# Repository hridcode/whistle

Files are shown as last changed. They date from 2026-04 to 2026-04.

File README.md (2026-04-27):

# Whistle

Whistle is the devboard of all time. It shares many similarities with the Raspberry Pi Pico, having the RP2040 SoC on board. However, this board aims to improve on the Pico's shortcomings. No more dealing with the haunting micro-USB port! This board uses a USB-C connection port. It also has 1 extra ADC pin, as well as an inbuilt digital-to-analog converter (DAC) and mono speaker amplifier, making it perfect for audio-integrated projects!

Oh, I almost forgot, it has LiPo battery charging!

# Photos

|Schematic|PCB|3D Render|
|---|---|---|
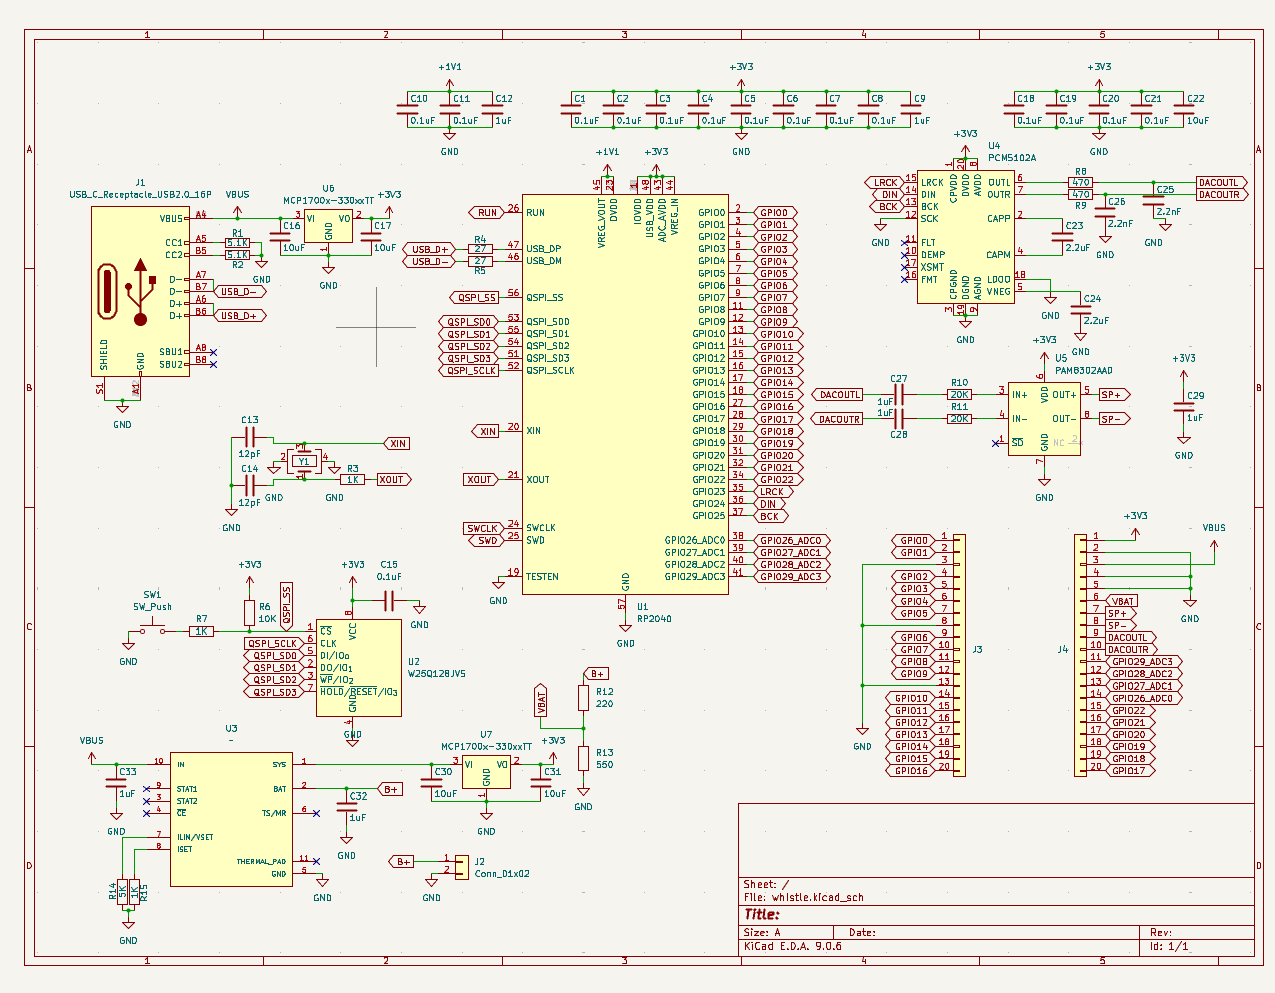
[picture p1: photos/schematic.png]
Schematic
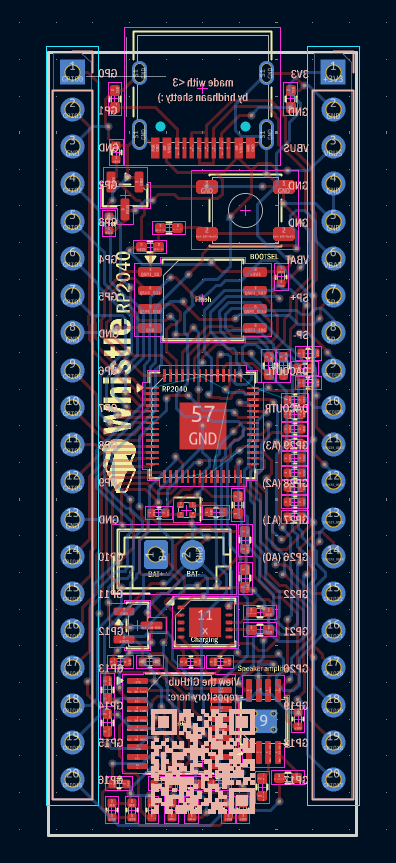
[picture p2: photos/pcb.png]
PCB
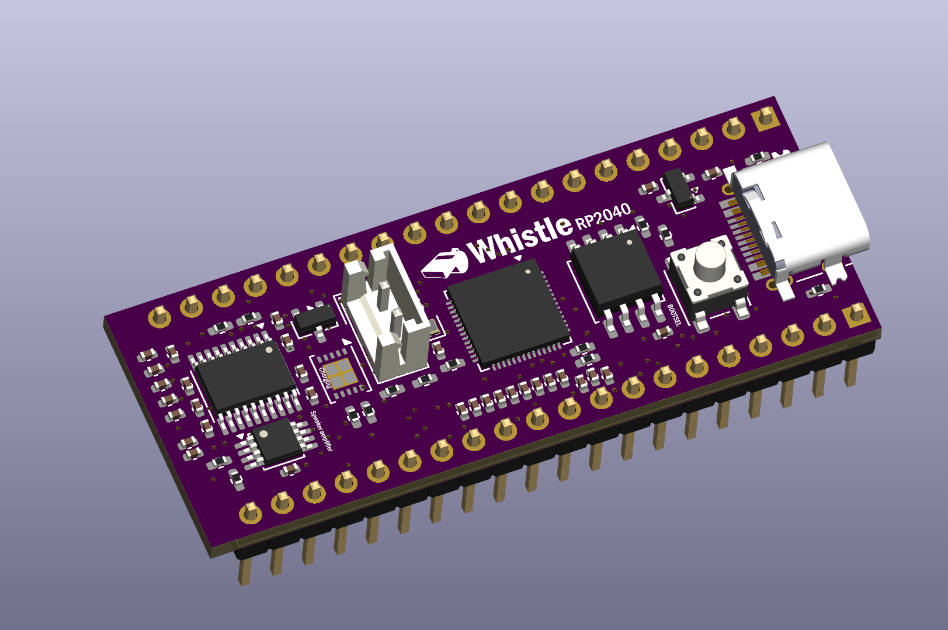
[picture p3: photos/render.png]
3D Render
||||

# BOM

|Item|Cost|Source|
|---|---|---|
|RP2040|$0.94|https://www.lcsc.com/product-detail/C2040.html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|
|Crystal oscillator|$0.07|https://www.lcsc.com/product-detail/C9002.html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|
|MCP1700 LDO, 3.3V|$0.98|https://www.lcsc.com/product-detail/C39051.html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|
|USB-C port, 16-pin|$0.08|https://www.lcsc.com/product-detail/C2988369.html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|
|W25Q128JVSIQ flash memory|$1.96|https://www.lcsc.com/product-detail/C97521.html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|
|PCM5102A DAC|$1.02|https://www.lcsc.com/product-detail/C107671.html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|
|PAM8302AAD speaker amplifier|$0.21|https://www.lcsc.com/product-detail/C112137.html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|
|BQ25185 battery charging IC|$1.66|https://www.lcsc.com/product-detail/C19725033.html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|
|SMD tactile switch, 6x6mm|$0.03|https://www.lcsc.com/product-detail/C49234152.html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|
|Pin headers|$0.38|https://www.lcsc.com/product-detail/C2938459.html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|
|PCB|$0.42|https://cart.jlcpcb.com/quote?stencilLayer=2&stencilWidth=21&stencilLength=54&stencilCounts=5&plateType=1|
|Stencil|$3.05|https://cart.jlcpcb.com/quote?stencilLayer=2&stencilWidth=21&stencilLength=54&stencilCounts=5&plateType=1|

Total: $10.81 ($7.76 w/o stencil)

# Notes

Have fun!

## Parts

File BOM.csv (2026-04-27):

Item | Cost | Source
RP2040 | 0.94 | https://www.lcsc.com/product-detail/C2040.html?s_z=s_p_RP2040
Crystal oscillator | 0.07 | https://www.lcsc.com/product-detail/C9002.html?s_z=s_q_CRYSTAL%252012MHZ
MCP1700 LDO (3.3V) | 0.98 | https://www.lcsc.com/product-detail/C39051.html?s_z=n_q_mcp1700%2520tt
USB-C port (16-pin) | 0.08 | https://www.lcsc.com/product-detail/C2988369.html?s_z=n_q_usb%2520c%252016
W25Q128JVSIQ flash memory | 1.96 | https://www.lcsc.com/product-detail/C97521.html?s_z=s_q_W25Q128JVSIQ
PCM5102A DAC | 1.02 | https://www.lcsc.com/product-detail/C107671.html?s_z=n_q_pcm5102a
PAM8302AAD speaker amplifier | 0.21 | https://www.lcsc.com/product-detail/C112137.html?s_z=n_q_pam8302aad
BQ25185 battery charging IC | 1.66 | https://www.lcsc.com/product-detail/C19725033.html?s_z=s_p_BQ25185DLHR
PCB | 0.42 | https://cart.jlcpcb.com/quote?stencilLayer=2&stencilWidth=21&stencilLength=54&stencilCounts=5&plateType=1
Stencil | 3.05 | https://cart.jlcpcb.com/quote?stencilLayer=2&stencilWidth=21&stencilLength=54&stencilCounts=5&plateType=1
SMD tactile switch (6x6mm) | 0.03 | https://www.lcsc.com/product-detail/C49234152.html?s_z=n_q_5x5mm%2520button
Pin headers | 0.24 | https://www.lcsc.com/product-detail/C2938459.html?s_z=h_q_pin%2520headers%252001x20
Total | 10.81

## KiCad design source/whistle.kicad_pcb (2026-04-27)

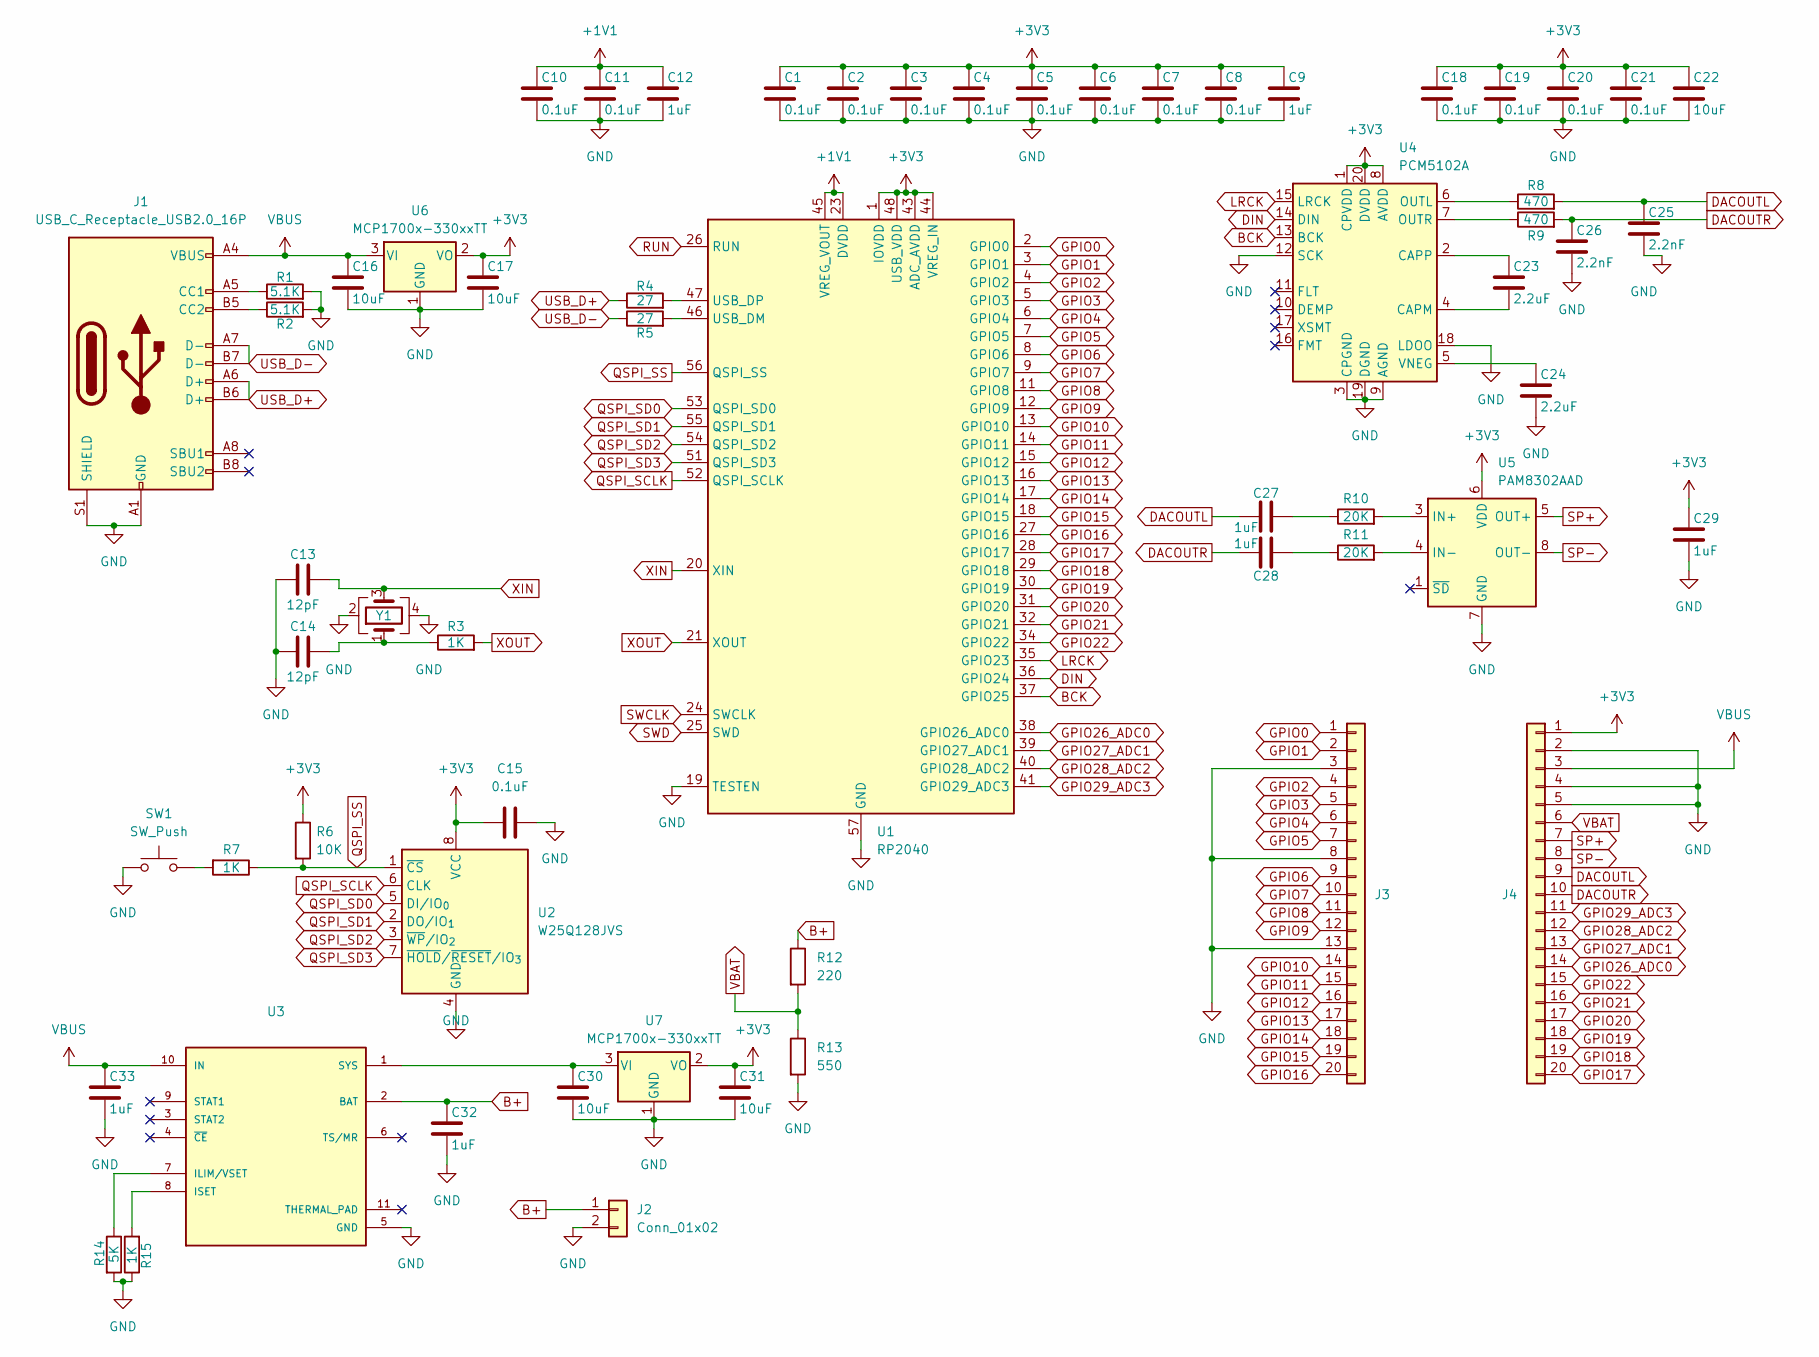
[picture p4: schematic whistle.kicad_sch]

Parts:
C1, C2, C3, C4, C5, C6, C7, C8, C10, C11, C15, C18, C19, C20, C21: 0.1uF; C_0402_1005Metric
C9, C12, C27, C28, C29, C32, C33: 1uF; C_0402_1005Metric
C13, C14: 12pF; C_0402_1005Metric
C16, C17, C22, C30, C31: 10uF; C_0402_1005Metric
C23, C24: 2.2uF; C_0402_1005Metric
C25, C26: 2.2nF; C_0402_1005Metric
J1: USB_C_Receptacle_USB2.0_16P; USB_C_Receptacle_HRO_TYPE-C-31-M-12
J2: Conn_01x02; JST_EH_B2B-EH-A_1x02_P2.50mm_Vertical
J3, J4: Conn_01x20; PinHeader_1x20_P2.54mm_Vertical
R1, R2: 5.1K; R_0402_1005Metric_Pad0.72x0.64mm_HandSolder
R3, R7, R15: 1K; R_0402_1005Metric_Pad0.72x0.64mm_HandSolder
R4, R5: 27; R_0402_1005Metric_Pad0.72x0.64mm_HandSolder
R6: 10K; R_0402_1005Metric_Pad0.72x0.64mm_HandSolder
R8, R9: 470; R_0402_1005Metric_Pad0.72x0.64mm_HandSolder
R10, R11: 20K; R_0402_1005Metric_Pad0.72x0.64mm_HandSolder
R12: 220; R_0402_1005Metric_Pad0.72x0.64mm_HandSolder
R13: 550; R_0402_1005Metric_Pad0.72x0.64mm_HandSolder
R14: 5K; R_0402_1005Metric_Pad0.72x0.64mm_HandSolder
SW1: SW_Push; SW_SPST_PTS647_Sx50
U1: RP2040; QFN-56-1EP_7x7mm_P0.4mm_EP3.2x3.2mm
U2: W25Q128JVS; SOIC-8_5.3x5.3mm_P1.27mm
U3: WSON-10-1EP_4x3mm_P0.5mm_EP2.2x2mm
U4: PCM5102A; TSSOP-20_4.4x6.5mm_P0.65mm
U5: PAM8302AAD; MSOP-8-1EP_3x3mm_P0.65mm_EP1.5x1.8mm_ThermalVias
U6, U7: MCP1700x-330xxTT; SOT-23
Y1: Crystal_GND24; Crystal_SMD_1210-4Pin_1.2x1.0mm

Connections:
+1V1: C10.1, C11.1, C12.1, U1.23 (DVDD), U1.45 (VREG_VOUT), U1.50 (DVDD)
+3V3: C1.1, C2.1, C3.1, C4.1, C5.1, C6.1, C7.1, C8.1, C9.1, C15.1, C17.1, C18.1, C19.1, C20.1, C21.1, C22.1, C29.1, C31.1, J4.1, R6.1, U1.1 (IOVDD), U1.10 (IOVDD), U1.22 (IOVDD), U1.33 (IOVDD), U1.42 (IOVDD), U1.43 (ADC_AVDD), U1.44 (VREG_IN), U1.48 (USB_VDD), U1.49 (IOVDD), U2.8 (VCC), U4.1 (CPVDD), U4.8 (AVDD), U4.20 (DVDD), U5.6 (VDD), U6.2 (VO), U7.2 (VO)
B+: C32.1, J2.1, R12.1, U3.2 (BAT)
BCK: U1.37 (GPIO25), U4.13 (BCK)
DACOUTL: C25.1, C27.1, J4.9, R8.2
DACOUTR: C26.1, C28.2, J4.10, R9.2
DIN: U1.36 (GPIO24), U4.14 (DIN)
GPIO0: J3.1, U1.2 (GPIO0)
GPIO1: J3.2, U1.3 (GPIO1)
GPIO2: J3.4, U1.4 (GPIO2)
GPIO3: J3.5, U1.5 (GPIO3)
GPIO4: J3.6, U1.6 (GPIO4)
GPIO5: J3.7, U1.7 (GPIO5)
GPIO6: J3.9, U1.8 (GPIO6)
GPIO7: J3.10, U1.9 (GPIO7)
GPIO8: J3.11, U1.11 (GPIO8)
GPIO9: J3.12, U1.12 (GPIO9)
GPIO10: J3.14, U1.13 (GPIO10)
GPIO11: J3.15, U1.14 (GPIO11)
GPIO12: J3.16, U1.15 (GPIO12)
GPIO13: J3.17, U1.16 (GPIO13)
GPIO14: J3.18, U1.17 (GPIO14)
GPIO15: J3.19, U1.18 (GPIO15)
GPIO16: J3.20, U1.27 (GPIO16)
GPIO17: J4.20, U1.28 (GPIO17)
GPIO18: J4.19, U1.29 (GPIO18)
GPIO19: J4.18, U1.30 (GPIO19)
GPIO20: J4.17, U1.31 (GPIO20)
GPIO21: J4.16, U1.32 (GPIO21)
GPIO22: J4.15, U1.34 (GPIO22)
GPIO26_ADC0: J4.14, U1.38 (GPIO26_ADC0)
GPIO27_ADC1: J4.13, U1.39 (GPIO27_ADC1)
GPIO28_ADC2: J4.12, U1.40 (GPIO28_ADC2)
GPIO29_ADC3: J4.11, U1.41 (GPIO29_ADC3)
LRCK: U1.35 (GPIO23), U4.15 (LRCK)
unnamed: C14.2, R3.1, Y1.1
unnamed: C27.2, R10.1
unnamed: C28.1, R11.1
unnamed: J1.A5 (CC1), R1.1
unnamed: J1.B5 (CC2), R2.1
unnamed: R7.2, SW1.2
unnamed: R5.2, U1.46 (USB_DM)
unnamed: R4.2, U1.47 (USB_DP)
unnamed: R14.1, U3.7 (ILIM/VSET)
unnamed: R15.2, U3.8 (ISET)
unnamed: C30.1, U3.1 (SYS), U7.3 (VI)
unnamed: C23.2, U4.4 (CAPM)
unnamed: C23.1, U4.2 (CAPP)
unnamed: R8.1, U4.6 (OUTL)
unnamed: R9.1, U4.7 (OUTR)
unnamed: R10.2, U5.3 (IN+)
unnamed: R11.2, U5.4 (IN-)
QSPI_SCLK: U1.52 (QSPI_SCLK), U2.6 (CLK)
QSPI_SD0: U1.53 (QSPI_SD0), U2.5 (DI/IO_{0})
QSPI_SD1: U1.55 (QSPI_SD1), U2.2 (DO/IO_{1})
QSPI_SD2: U1.54 (QSPI_SD2), U2.3 (~WP/IO_{2})
QSPI_SD3: U1.51 (QSPI_SD3), U2.7 (~HOLD/~RESET/IO_{3})
QSPI_SS: R6.2, R7.1, U1.56 (QSPI_SS), U2.1 (~CS)
RUN: U1.26 (RUN)
SP+: J4.7, U5.5 (OUT+)
SP-: J4.8, U5.8 (OUT-)
SWCLK: U1.24 (SWCLK)
SWD: U1.25 (SWD)
USB_D+: J1.A6 (D+), J1.B6 (D+), R4.1
USB_D-: J1.A7 (D-), J1.B7 (D-), R5.1
VBAT: J4.6, R12.2, R13.1
VBUS: C16.1, C33.1, J1.A4 (VBUS), J1.A9 (VBUS), J1.B4 (VBUS), J1.B9 (VBUS), J4.3, U3.10 (IN), U6.3 (VI)
XIN: C13.2, U1.20 (XIN), Y1.3
XOUT: R3.2, U1.21 (XOUT)

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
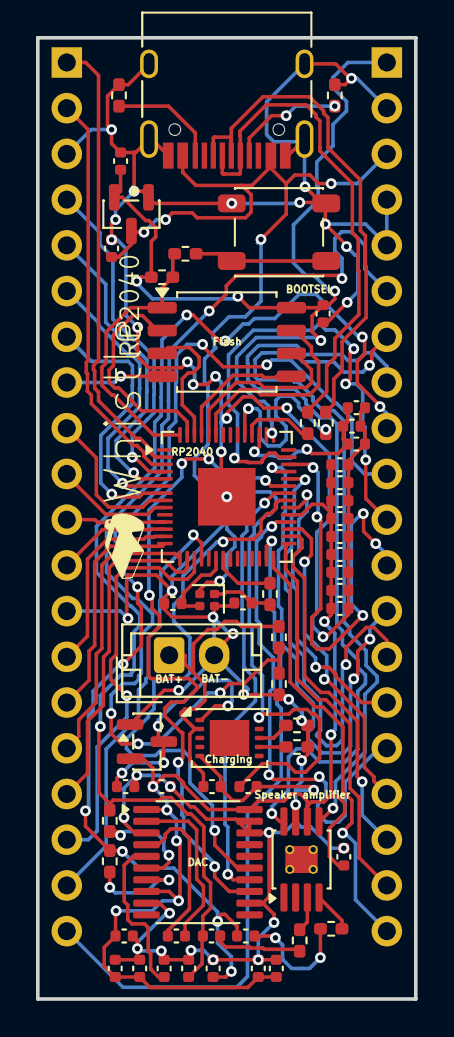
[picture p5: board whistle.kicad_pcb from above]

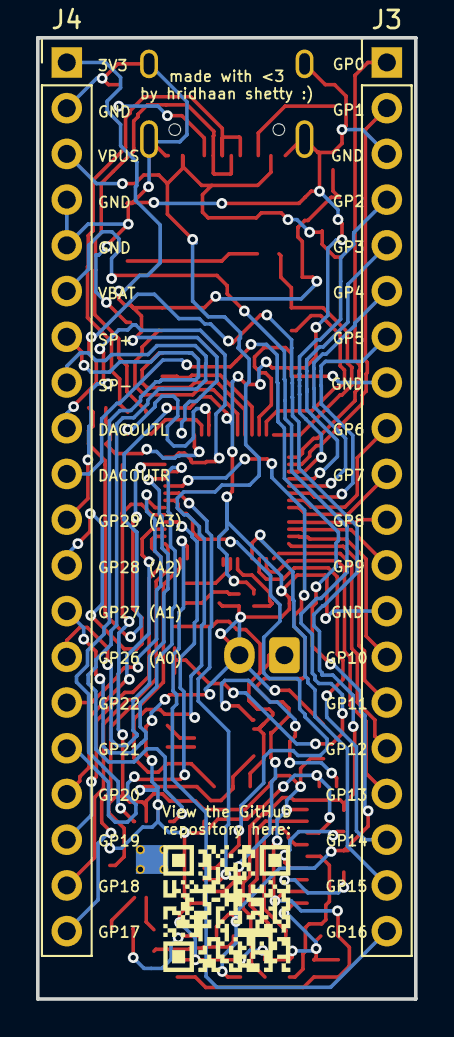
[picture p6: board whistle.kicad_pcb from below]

Board: 2 copper layers, 21.0 x 53.4 mm, 61 parts (2 on the bottom side), 68 nets.

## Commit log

2026-04-27 Added production, source, BOM and updated README.md
    [BOM.csv, whistle.kicad_pcb, whistle.kicad_sch]
2026-04-27 Updated BOM
    [BOM.csv]
